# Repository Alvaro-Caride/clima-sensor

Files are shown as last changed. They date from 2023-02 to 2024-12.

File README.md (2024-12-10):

# Clima Sensor

## Intention

This project is intended to deploy a clima sensoring net in the Galicia Supercomputing Center CESGA.

We started by looking for some reliable clima sensors to deploy and now a days, the state of the project is that we have our firts sensor integrated within the metrics database. As it just have happened, the sensor is still in a testing face but we are whilling to add more sensors to the net iterating the process described below.

## Overview

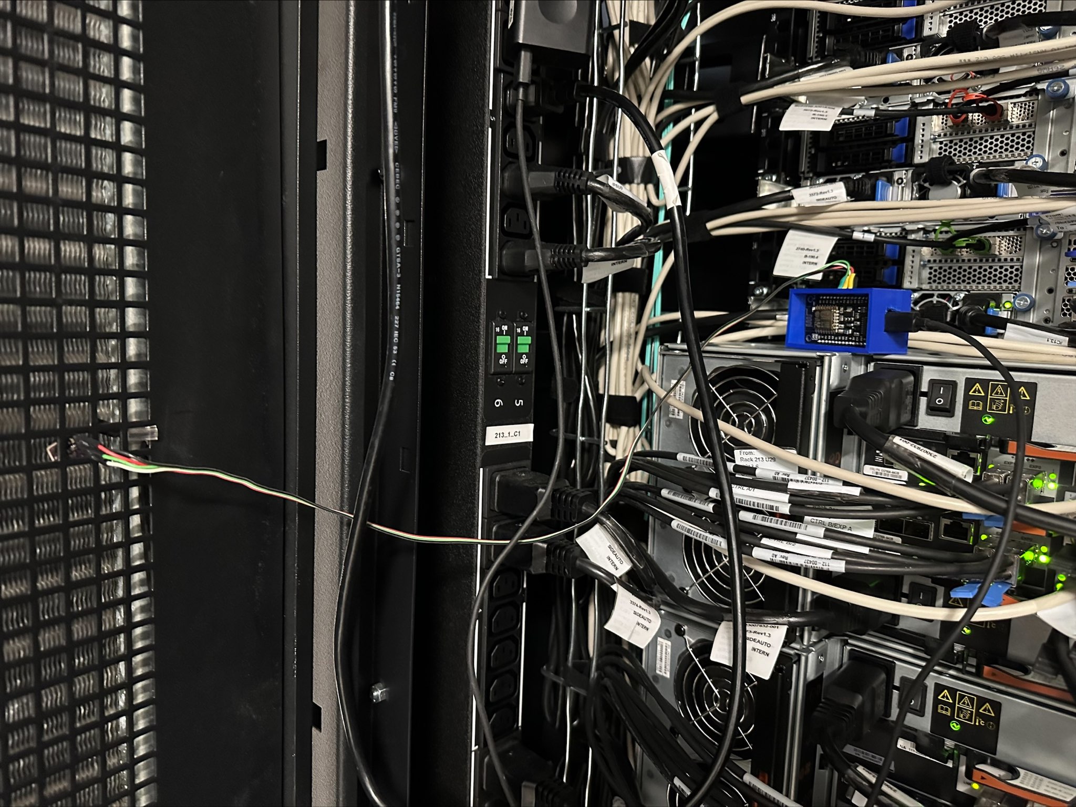
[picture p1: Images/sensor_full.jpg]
Clima_Sensor Sensor placed in the back rack space


The clima sensor project has 2 main separable parts. One is from device perspective, hardware, firmware and calibration while the other stands for publushing readings into our database and being able to visualize it with our production tools. 

From the hardware perspective, we have choosen a NodeMCU and a BME280. 
Our closest reference is this one from [Random Nerd Tutorials](https://randomnerdtutorials.com/esp8266-bme280-arduino-ide/).

We have modified firmware to export application/json data types to make it easier for us to integrate those readings with our database.

Also we have performed calibration to the sensor and many tests are still ongoing.

For the publishing part, we have used systemd timers wich points to a python script that makes the publication. We are moving into this direction to try to unify the way we input data into our database. This timer is deployed in an administration virtual machine instanced with this purpose in mind, to unify here most of our metric exporters in the future.

We have also design a enclosure and print it with our printer. this design is quite rude and it's also being refined. You can find some valid designs in [Enclosure](https://gitlab.com/cesga-sistemas/clima_sensor/-/tree/main/Enclosure).

## [Firmware](https://gitlab.com/cesga-sistemas/clima_sensor/-/blob/main/Firmware/Cesga-Prototype-Sensor-text-based.ino)

Starting from the firmware, you need to include a specific Url to add esp8266 board's to the Arduino's Idle. Go to Files>Preferences and on the "Additional boards" urls section paste de next URL: http://arduino.esp8266.com/stable/package_esp8266com_index.json 

Once you have added this URL, you can search for the board in the board manager. Tools>boards>board manager.

Also, you need to include some libraries in the Ilde in order to work.

Libraries needed:

``` c++
#include <ESP8266WiFi.h>
#include <Wire.h>
#include <Adafruit_BME280.h>
#include <Adafruit_Sensor.h>
#include <ArduinoJson.h>
```

From here, modifying some parts of the firmware is quite straightforward. Add your wifi credentials, modify what the server prints and adjust calibration. Also, all these parts are well explained in the ```.io``` file.

## Calibration

For the calibration part, we have performed a by-comparison calibration for the temperature and salt methods for relative humidity sensing. We have not performed a pressure calibration as this is not an important aspect of our needs.

We have used a calibration-trusted thermometer to compare the measures with our sensor. As the differences were pretty stable we have done a change in the origin to adjust the values. For the Relative Humidity part, we have done a *NaCl* calibration performing a measure for more than 12 hours and a range of 7 degrees celsius. We could have performed another salt point for the calibration but we have considered that just one is enough for our needs.

This process should be repeated for each sensor we introduce to the system. We could also simply do comparison calibration for both magnitudes but we also could parallelize it so would be better to repeat the process.

## [Publication](https://gitlab.com/cesga-sistemas/clima_sensor/-/blob/main/cesga-sensor_opentsdb/publish_cesga_sensor.py)

To read the values of the sensor we have implemented a systemd timer in a virtual machine that runs the publishing program every 5 minutes. We could easily increase granularity by modifing the timer but the sensor has some problems when your really speedups the readings to the order of +6 readings per minute.

## [Enclosure](https://gitlab.com/cesga-sistemas/clima_sensor/-/tree/main/Enclosure)

We have designed and print a simple enclosure just to protect the main body with some holes to do all the cabling. We have added a cover to close the device.

## Cabling

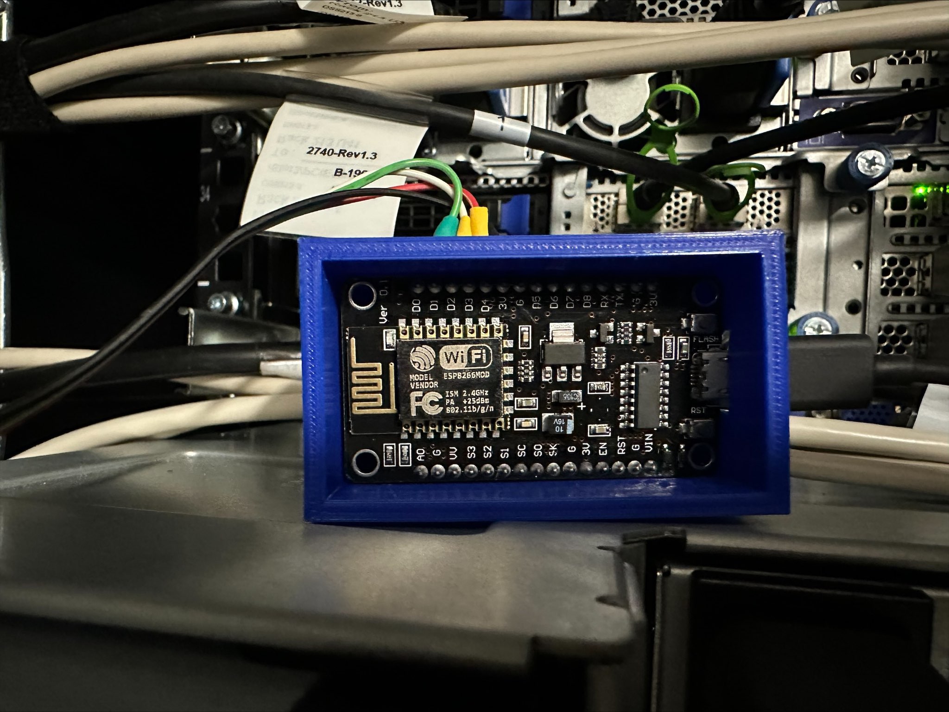
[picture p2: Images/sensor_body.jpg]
Sensor body


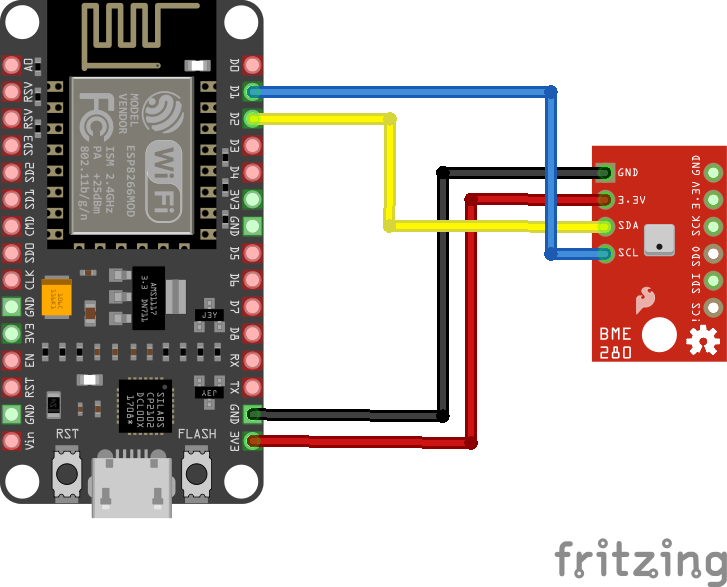
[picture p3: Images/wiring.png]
Sensor cabling wiring map


**I2c vs SPI**: If you prefer to conect the BME with SPI instead of I2 you should buy a BME unit with 6 pins instead of 4. The main advantage of connecting the sensor in this way is that you can easily add another sensing unit to the node and ask for their data separatelly defining 2 diferent addreses. The addres is asigned acordingly to the cabling and this solution should be the main way of building 2 ends-sensors.

## Known issues

+ If the temperature increases to a certain value, the sensor starts wiping data and gets harder to send and read values. We could try to improve this by better isolating the core unit and placing it wisely. This temperature is about 49ºC for at least 3 hours for the sensor to start to fail.

+ If we ask the sensor to read more than one measure every 10 seconds, the publication becomes noisy. This is because the sensor starts to not respond well for every measure.

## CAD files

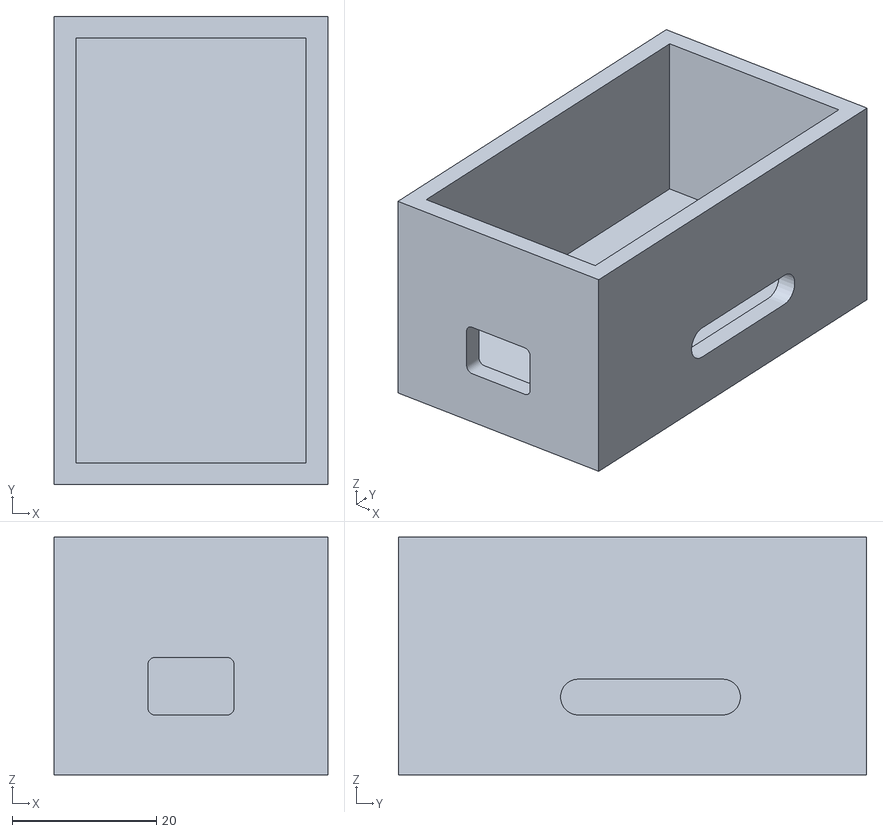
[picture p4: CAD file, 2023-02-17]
Enclosure/caja_NodeMcu.stl
38.0 x 65.0 x 33.0

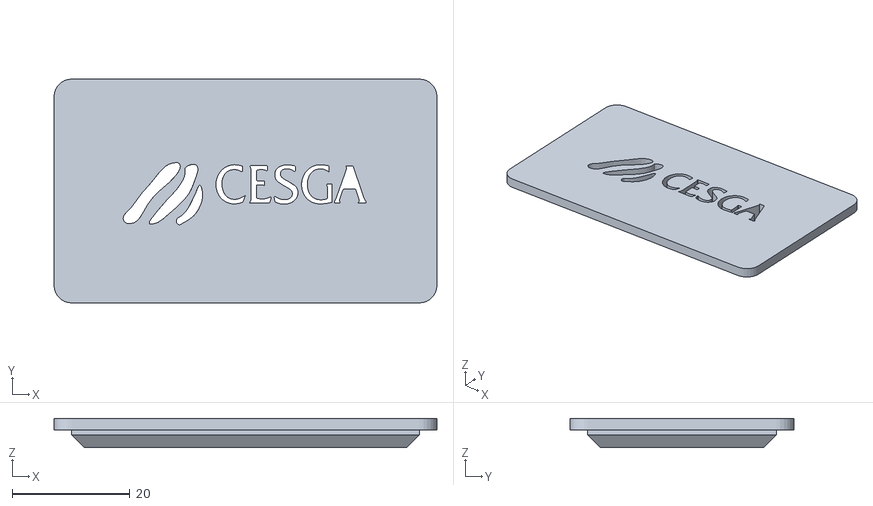
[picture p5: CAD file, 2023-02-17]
Enclosure/tapa_NodeMcu-Body.stl
65.0 x 38.0 x 5.00

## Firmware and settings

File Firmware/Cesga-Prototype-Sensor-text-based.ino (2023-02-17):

/*********

  Alvaro Caride
  Modified from Rui Santos project in https://randomnerdtutorials.com

  Connect to serial monitor to DEBUG
*********/

// Load Wi-Fi library
#include <ESP8266WiFi.h>
#include <Wire.h>
#include <Adafruit_BME280.h>
#include <Adafruit_Sensor.h>
#include <ArduinoJson.h>

//uncomment the following lines if you're using SPI
/*#include <SPI.h>
#define BME_SCK 14
#define BME_MISO 12
#define BME_MOSI 13
#define BME_CS 15*/



Adafruit_BME280 bme; // I2C
//Adafruit_BME280 bme(BME_CS); // hardware SPI
//Adafruit_BME280 bme(BME_CS, BME_MOSI, BME_MISO, BME_SCK); // software SPI

// Replace with your network credentials
const char* ssid     = "**************";            // Add your network ssid
const char* password = "**************";            // Add your network password

// Set web server port number to 80
WiFiServer server(80);

// Variable to store the HTTP request
String header;

void setup() {
  Serial.begin(115200);
  bool status;

  // default settings
  // (you can also pass in a Wire library object like &Wire2)
  //status = bme.begin();  


  if (!bme.begin(0x76)) {
    Serial.println("Could not find a valid BME280 sensor, check wiring!");
    while (1);
  }

  // Connect to Wi-Fi network with SSID and password
  Serial.print("Connecting to ");
  Serial.println(ssid);
  WiFi.begin(ssid, password);
  while (WiFi.status() != WL_CONNECTED) {
    delay(500);
    Serial.print(".");
  }
  // Print local IP address and start web server
  Serial.println("");
  Serial.println("WiFi connected.");
  Serial.println("IP address: ");
  Serial.println(WiFi.localIP());
  server.begin();
}

void loop(){
  WiFiClient client = server.available();   // Listen for incoming clients

  if (client) {                             // If a new client connects,
    Serial.println("New Client.");          // print a message out in the serial port
    String currentLine = "";                // make a String to hold incoming data from the client
    while (client.connected()) {            // loop while the client's connected
      if (client.available()) {             // if there's bytes to read from the client,
        char c = client.read();             // read a byte, then
        Serial.write(c);                    // print it out the serial monitor
        header += c;
        if (c == '\n') {                    // if the byte is a newline character
          // if the current line is blank, you got two newline characters in a row.
          // that's the end of the client HTTP request, so send a response:
          if (currentLine.length() == 0) {
            // HTTP headers always start with a response code (e.g. HTTP/1.1 200 OK)
            // and a content-type so the client knows what's coming, then a blank line:
            client.println("HTTP/1.1 200 OK");
            //client.println("Content-type:text/html");
            client.println("Content-type:application/json");
            client.println("Connection: close");
            client.println();
            // Pruebas para la publicación y lectura más cómodas con application/json
            // Respuesta en json
            StaticJsonDocument<200> doc;
            float temp = bme.readTemperature() + 0.16;
            float pressure = bme.readPressure() / 100.0F;
            float humidity = bme.readHumidity() + 8.3;
            // Use calibrated values to calc the dewpoint
            float dewpoint = (237.7*((17.27*temp/(237.7+temp))+(log(humidity/100)/log(2.718))))/(17.27-((17.27*temp/(237.7+temp))+(log(humidity/100)/log(2.718))));            
            
            doc["temp"] = temp;
            doc["pressure"] = pressure;
            doc["humidity"] = humidity;
            doc["dewpoint"] = dewpoint;

            char buffer[100];
            serializeJson(doc, buffer);
            Serial.println(buffer);           
            client.println(buffer);




            // If we prefer HTML text based we can still use this lines
            // Display the HTML web page
            //client.println("<!DOCTYPE html><html>"); 
            // Web Page Heading
            //client.println("<main>Temperatura Celsius ");
            //client.println(bme.readTemperature() + 0.16);      // Valor extraido de la calibración 
            //client.println(" Presion hPa ");
            //client.println(bme.readPressure() / 100.0F);
            //client.println(" Humedad relativa % ");
            //client.println(bme.readHumidity() + 8.3);           // Calibrado con un punto con NaCl
            //client.println(" Punto de Rocio Celsius ");
            //client.println ((237.7*((17.27*bme .readTemperature()/(237.7+bme.readTemperature()))+(log(bme.readHumidity()/100)/log(2.718))))/(17.27-((17.27*bme.readTemperature()/(237.7+bme.readTemperature()))+(log(bme.readHumidity()/100)/log(2.718)))));
            //client.println("</main></body></html>");
            
            // The HTTP response ends with another blank line
            client.println();
            // Break out of the while loop
            break;
          } else { // if you got a newline, then clear currentLine
            currentLine = "";
          }
        } else if (c != '\r') {  // if you got anything else but a carriage return character,
          currentLine += c;      // add it to the end of the currentLine
        }
      }
    }
    // Clear the header variable
    header = "";
    // Close the connection
    client.stop();
    Serial.println("Client disconnected.");
    Serial.println("");
  }
}

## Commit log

2023-02-17 Necesary arhives to deploy the sensor in CESGA
2023-02-17 Added desings and rebuilding some namings and basic files
    [caja_NodeMcu.stl, tapa_NodeMcu-Body.stl]
2023-03-13 wiring corrected
